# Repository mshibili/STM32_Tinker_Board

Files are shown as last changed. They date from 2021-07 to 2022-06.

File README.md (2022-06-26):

# STM32_Tinker_Board
 STM32F405RGT6 based development board including
 -USB micro port with EM protecton.
 -Serial Wire Debug port for programming.
 -MP2359 buck-regulator and indicator leds.
 
 (Copper pour not assigned. Library of MP3259 may not be fetched by the KI-Cad. Need fixes:-|)
 
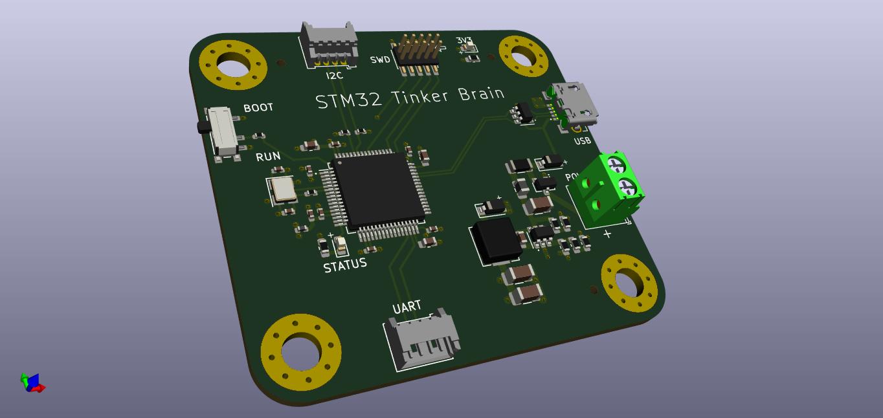
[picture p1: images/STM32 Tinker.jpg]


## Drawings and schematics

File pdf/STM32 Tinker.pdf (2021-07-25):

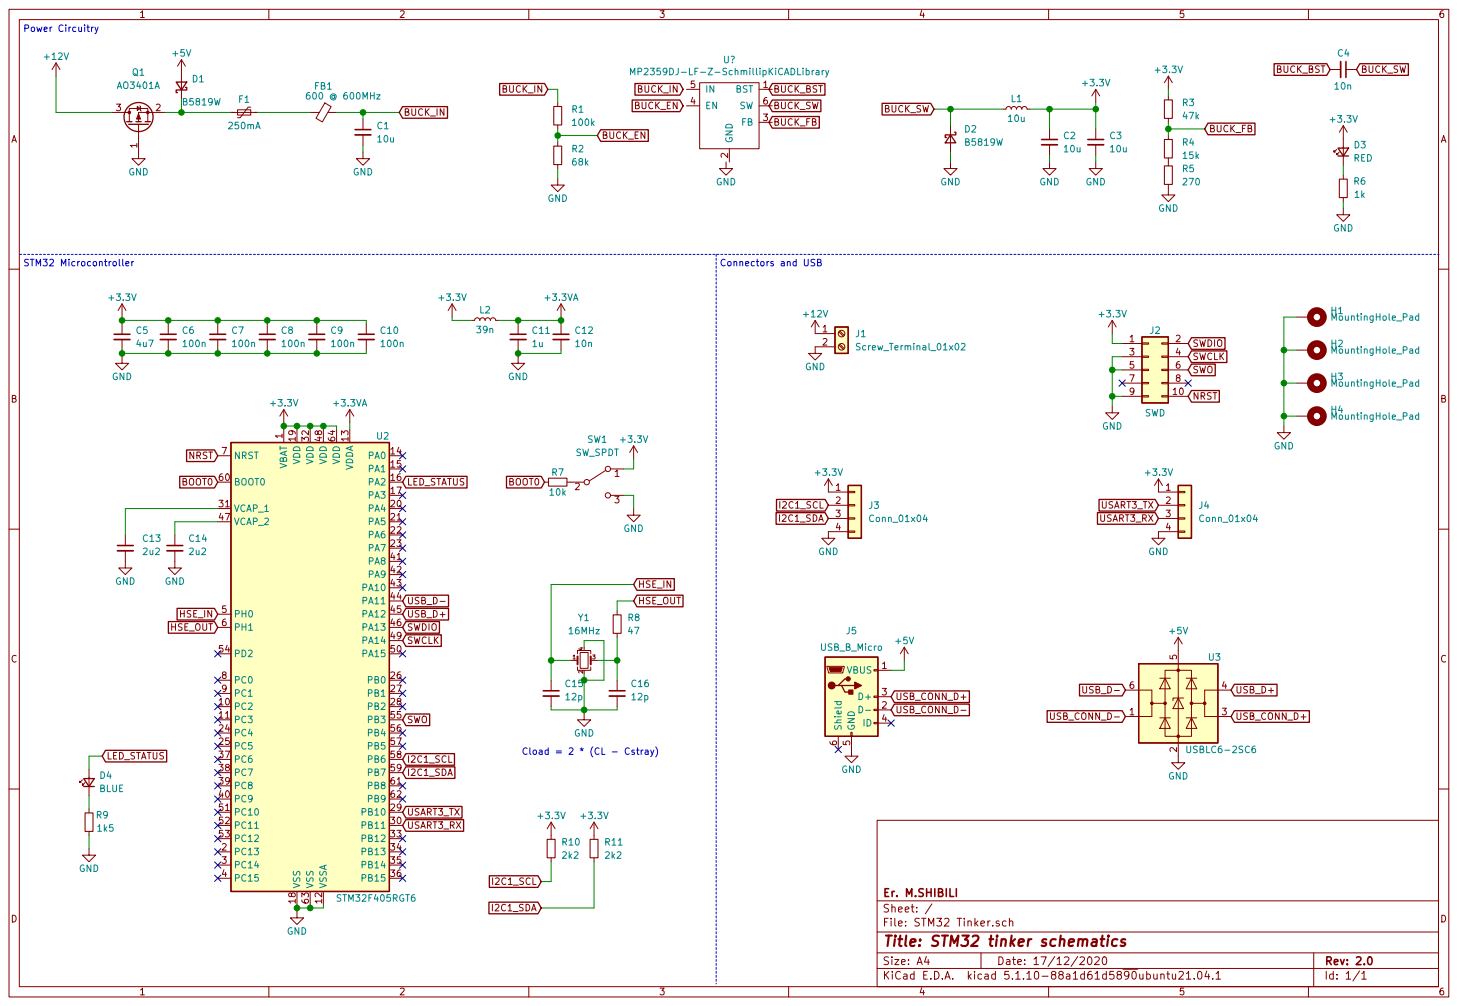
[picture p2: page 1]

7 9 | 8

1 VCAP_1 31 VCAP_2 47 VDD 19 VDD 32 VDD 48 VDD 64 VDDA 13 VSS 18 VSS 63 VSSA 12 U2 STM32F405RGT6 C14

File: STM32 Tinker.sch Sheet: / Er. M.SHIBILI

Id: 1/1 Title: STM32 tinker schematics

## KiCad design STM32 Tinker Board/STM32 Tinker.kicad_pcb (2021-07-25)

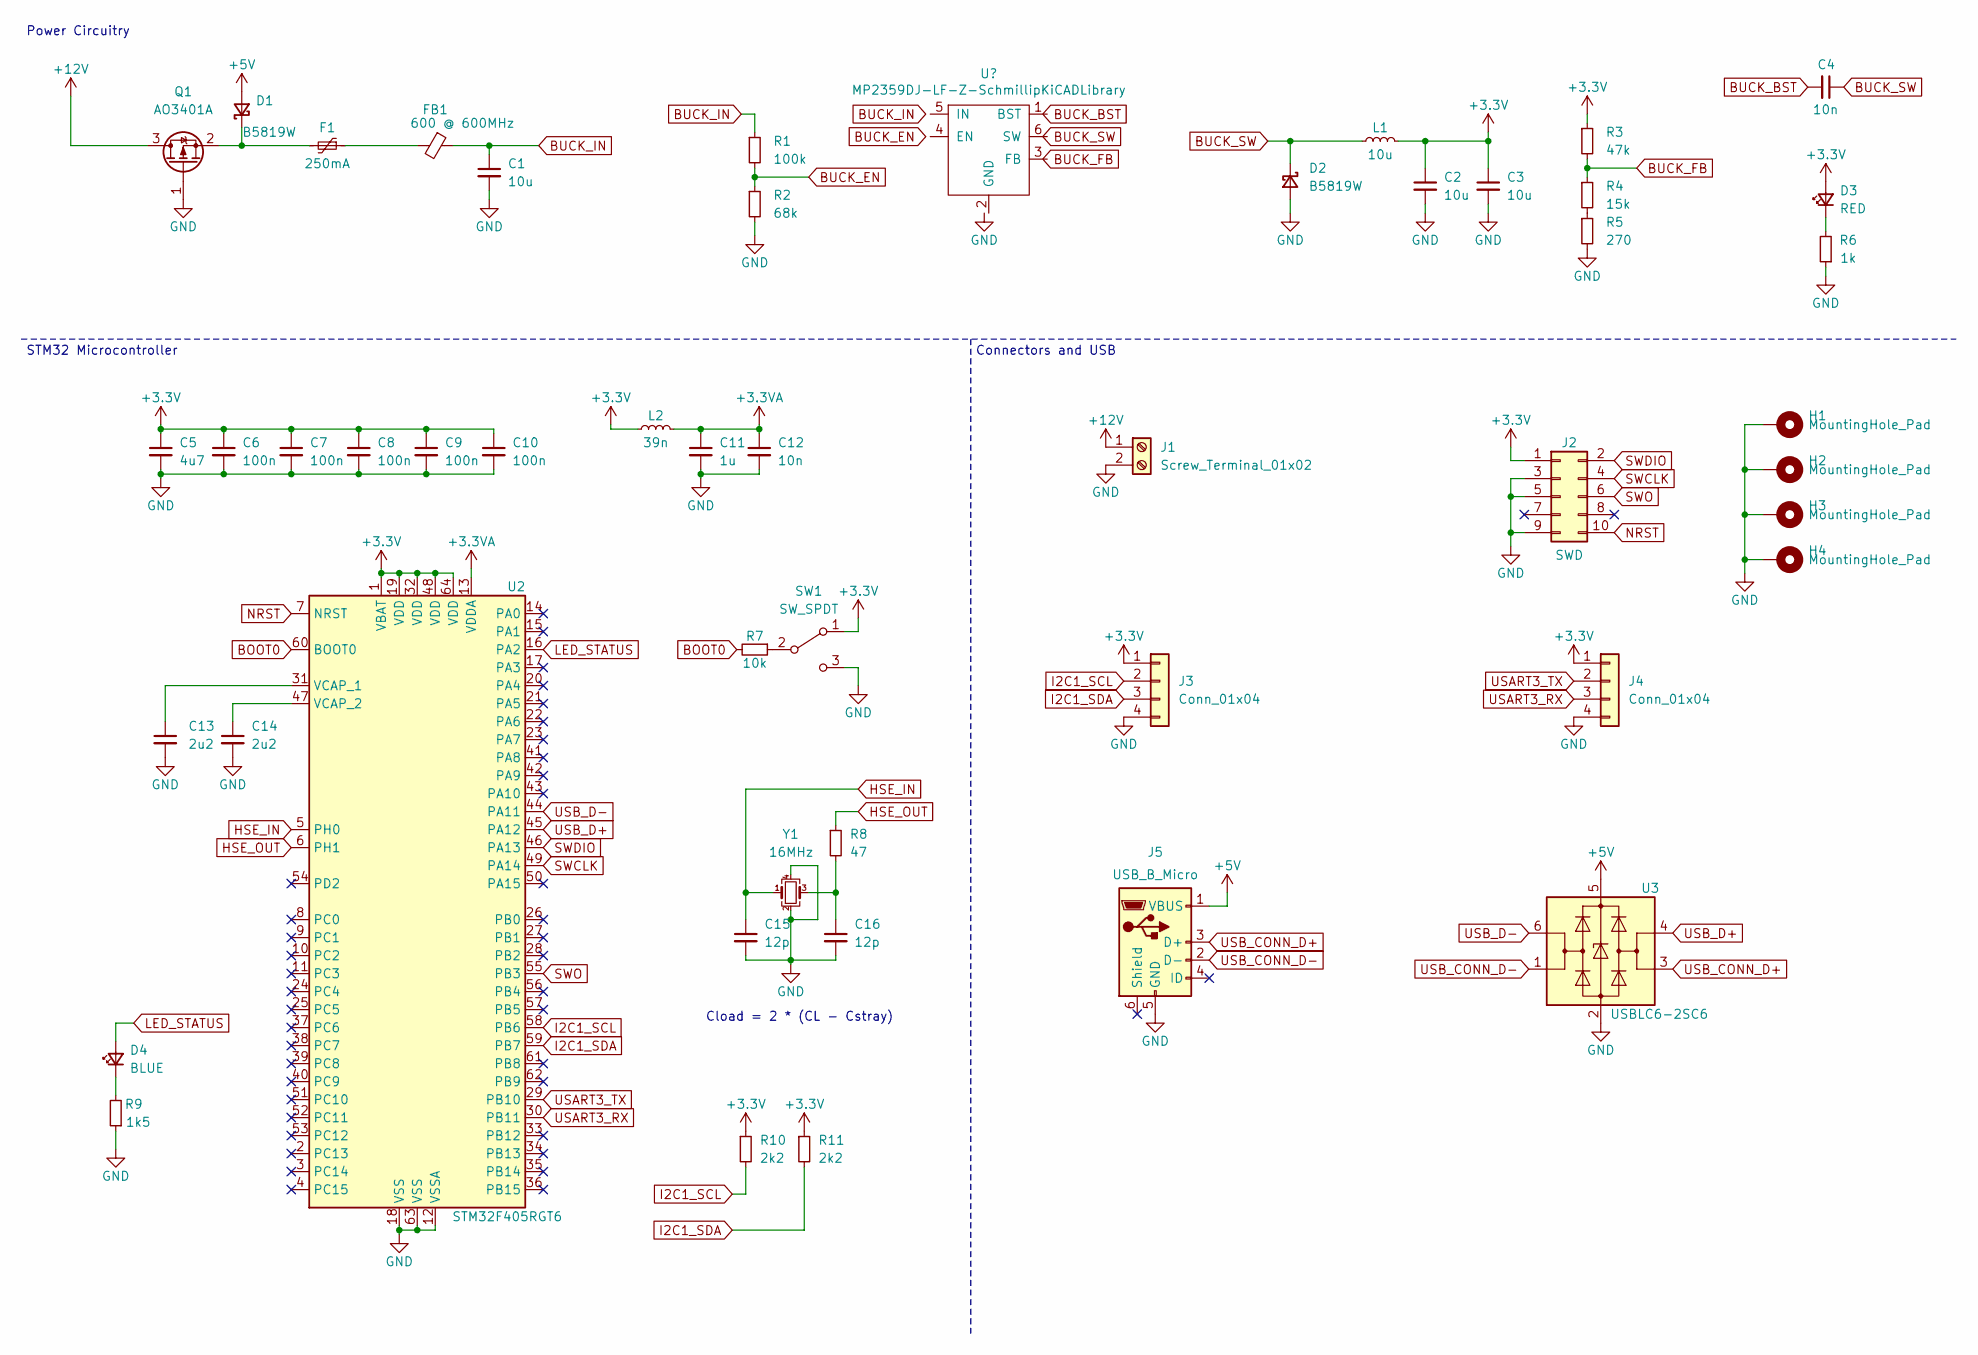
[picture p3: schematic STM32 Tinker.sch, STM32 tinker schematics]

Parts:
C1, C2, C3: 10u
C4, C12: 10n
C5: 4u7
C6, C7, C8, C9, C10: 100n
C11: 1u
C13, C14: 2u2
C15, C16: 12p
D1, D2: B5819W
D3: RED
D4: BLUE
F1: 250mA
FB1: 600 @ 600MHz
H1, H2, H3, H4: MountingHole_Pad
J1: Screw_Terminal_01x02
J2: SWD
J3, J4: Conn_01x04
J5: USB_B_Micro
L1: 10u
L2: 39n
Q1: AO3401A; SOT-23
R1: 100k
R2: 68k
R3: 47k
R4: 15k
R5: 270
R6: 1k
R7: 10k
R8: 47
R9: 1k5
R10, R11: 2k2
SW1: SW_SPDT
U2: STM32F405RGT6; LQFP-64_10x10mm_P0.5mm
U3: USBLC6-2SC6; SOT-23-6
Y1: 16MHz

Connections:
+3.3VA: C11.1, C12.1, L2.2, U2.13 (VDDA)
+3V3: C2.1, C3.1, C5.1, C6.1, C7.1, C8.1, C9.1, C10.1, D3.2 (A), J2.1, J3.1, J4.1, L1.2, L2.1, R3.1, R10.1, R11.1, SW1.1 (A), U2.1 (VBAT), U2.19 (VDD), U2.32 (VDD), U2.48 (VDD), U2.64 (VDD)
+5V: D1.2 (A), J5.1 (VBUS), U3.5 (VBUS)
+12V: J1.1, Q1.3 (D)
BOOT0: R7.2, U2.60 (BOOT0)
BUCK_BST: C4.2; also elsewhere on the board
BUCK_EN: R1.2, R2.1; also elsewhere on the board
BUCK_FB: R3.2, R4.1; also elsewhere on the board
BUCK_IN: C1.1, FB1.1, R1.1; also elsewhere on the board
BUCK_SW: C4.1, D2.1 (K), L1.1; also elsewhere on the board
GND: C1.2, C2.2, C3.2, C5.2, C6.2, C7.2, C8.2, C9.2, C10.2, C11.2, C12.2, C13.2, C14.2, C15.2, C16.2, D2.2 (A), H1.1, H2.1, H3.1, H4.1, J1.2, J2.3, J2.5, J2.9, J3.4, J4.4, J5.5 (GND), Q1.1 (G), R2.2, R5.2, R6.1, R9.1, SW1.3 (C), U2.12 (VSSA), U2.18 (VSS), U2.63 (VSS), U3.2 (GND), Y1.2, Y1.4; also elsewhere on the board
HSE_IN: C15.1, U2.5 (PH0), Y1.1
HSE_OUT: R8.1, U2.6 (PH1)
I2C1_SCL: J3.2, R10.2, U2.58 (PB6)
I2C1_SDA: J3.3, R11.2, U2.59 (PB7)
LED_STATUS: D4.2 (A), U2.16 (PA2)
NRST: J2.10, U2.7 (NRST)
unnamed: C13.1, U2.31 (VCAP_1)
unnamed: C14.1, U2.47 (VCAP_2)
unnamed: C16.1, R8.2, Y1.3
unnamed: D1.1 (K), F1.2, Q1.2 (S)
unnamed: D3.1 (K), R6.2
unnamed: D4.1 (K), R9.2
unnamed: F1.1, FB1.2
unnamed: R4.2, R5.1
unnamed: R7.1, SW1.2 (B)
SWCLK: J2.4, U2.49 (PA14)
SWDIO: J2.2, U2.46 (PA13)
SWO: J2.6, U2.55 (PB3)
USART3_RX: J4.3, U2.30 (PB11)
USART3_TX: J4.2, U2.29 (PB10)
USB_CONN_D+: J5.3 (D+), U3.3 (I/O2)
USB_CONN_D-: J5.2 (D-), U3.1 (I/O1)
USB_D+: U2.45 (PA12), U3.4 (I/O2)
USB_D-: U2.44 (PA11), U3.6 (I/O1)

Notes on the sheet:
Cload = 2 * (CL - Cstray)
STM32 Microcontroller
Power Circuitry
Connectors and USB

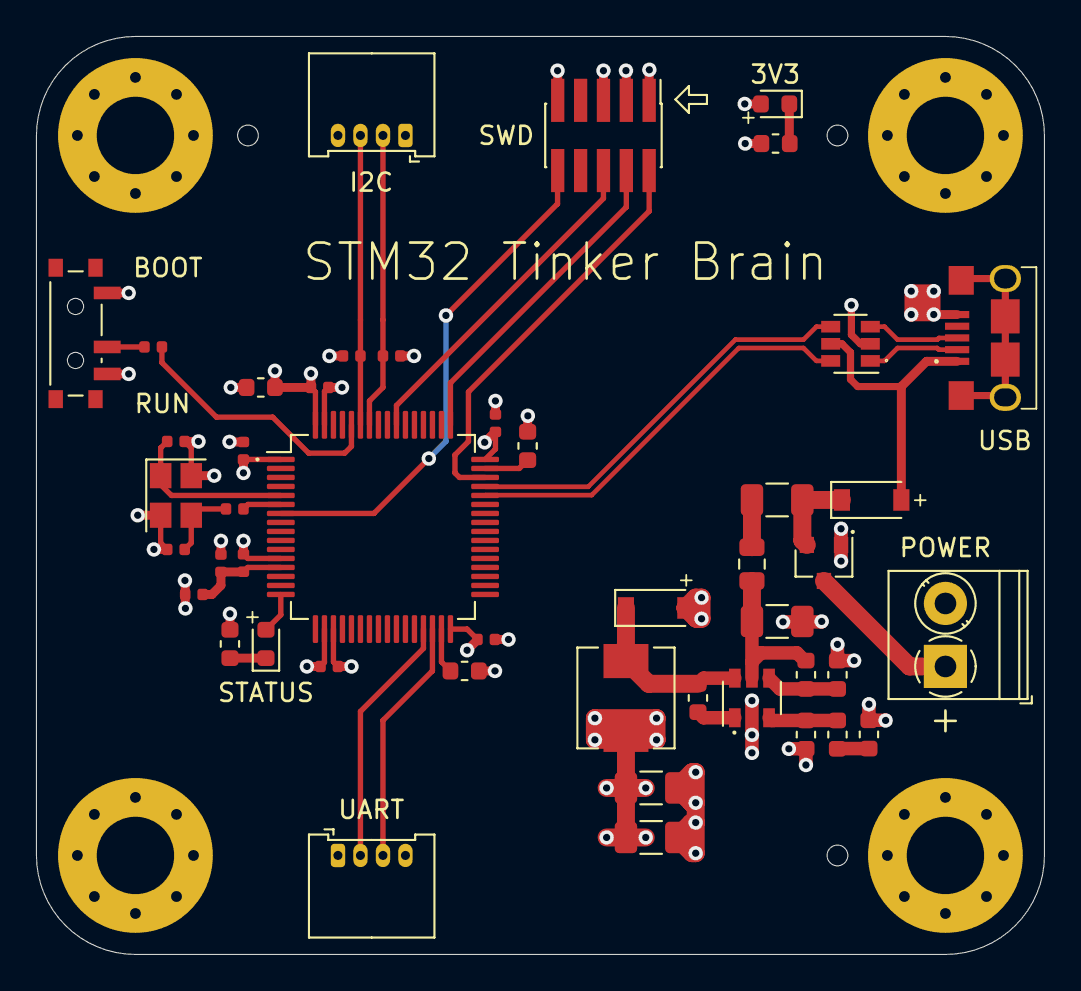
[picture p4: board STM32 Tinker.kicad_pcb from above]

Board: 4 copper layers, 56.0 x 51.0 mm, 50 parts (0 on the bottom side), 35 nets.

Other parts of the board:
U1: MP2359DJ-LF-Z; SOT-23-6

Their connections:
BUCK_BST: U1.1; also elsewhere on the board
BUCK_EN: U1.4; also elsewhere on the board
BUCK_FB: U1.3; also elsewhere on the board
BUCK_IN: U1.5; also elsewhere on the board
BUCK_SW: U1.6; also elsewhere on the board
GND: U1.2; also elsewhere on the board
